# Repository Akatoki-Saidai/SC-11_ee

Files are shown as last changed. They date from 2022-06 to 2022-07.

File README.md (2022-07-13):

# SC-11_ee

## Arduino Pin使用番号

## 各種センサ動作確認結果

<table>
    <tr>
        <td width="20%" rowspan="3">三軸加速度</td>
        <td>analogRead()で電圧を読んでシリアルモニタに表示することはできた</td>
    </tr>
    <tr>
        <td>ふってみてデータを見た感じ変化はしているのでちゃんと取れてる？</td>
    </tr>
    <tr>
        <td>生データを表示しているのでわかりにくいので，[m/s^2]表記への変換が必要</td>
    </tr>
    <tr>
        <td rowspan="3">3軸角速度</td>
        <td>https://n.mtng.org/ele/arduino/tutorial017.html</td>
    </tr>
    <tr>
        <td>レジスタ等の変更が必要らしい</td>
    </tr>
    <tr>
        <td>単位は [°/sec]</td>
    </tr>
    <tr>
        <td rowspan="4">BME280</td>
        <td>高度がマイナスになるのは海面気圧が問題？</td>
    </tr>
    <tr>
        <td>SC-10で購入したSwitchScience製のBME280で動作確認</td>
    </tr>
    <tr>
        <td>高度は↓のサイトを参照</td>
    </tr>
    <tr>
        <td>https://keisan.casio.jp/exec/system/1203469826</td>
    </tr>
        <tr>
        <td rowspan="3">DRV8835</td>
        <td>モーターを動かす時間がなかったのでLEDでテスト</td>
    </tr>
    <tr>
        <td>「加速」「減速」以外はLEDでは正常に動作</td>
    </tr>
    <tr>
        <td>「加速」は「減速」は確認できなかった（エラーは出てない）</td>
    </tr>
</table>

## モード定義

この セクションでは各モードの概要を説明する．

#### 待機モード (Mode-N)

- このモードでは基本的には「何もしない」というモードですが，以下のセンサーのキャリブレーション・実行準備を実施します．
  
  - 加速度センサー
  - 角速度センサー
  - 地磁気センサー
  - ブラシレスモーター

- 以下の定義を全て満たした場合に `Mode-A` に移行するものとする．
  
  1. Arduino Nanoが起動してから `30 sec` 以上経過している
  
  2. CanSatの高度が `TBD m` 以上である
  
  3. CanSatが落下を検知
     
     :pencil2: 落下を検知とは：未定義

#### 機体安定モード (Mode-A)

- このモードでは機体を安定させることに特化した（またはそれのみを実施する）モードである．
  - 機体がある程度安定したら，`Mode-B`に移行し，機体を的確に制御する．

#### 機体制御モード (Mode-B)

- このモードでは機体を制御させることに特化した（またはそれのみを実施する）モードである．特に，ゴールへの制御を実行する．
  - 機体制御が困難になった場合は，`Mode-A`に移行する．
  - ゴールから`TBD`m以内に入ったら`Mode-F`

#### 最終着地モード (Mode-F)

- このモードではゴールとの距離を維持したまま下降することのみに特化したモード

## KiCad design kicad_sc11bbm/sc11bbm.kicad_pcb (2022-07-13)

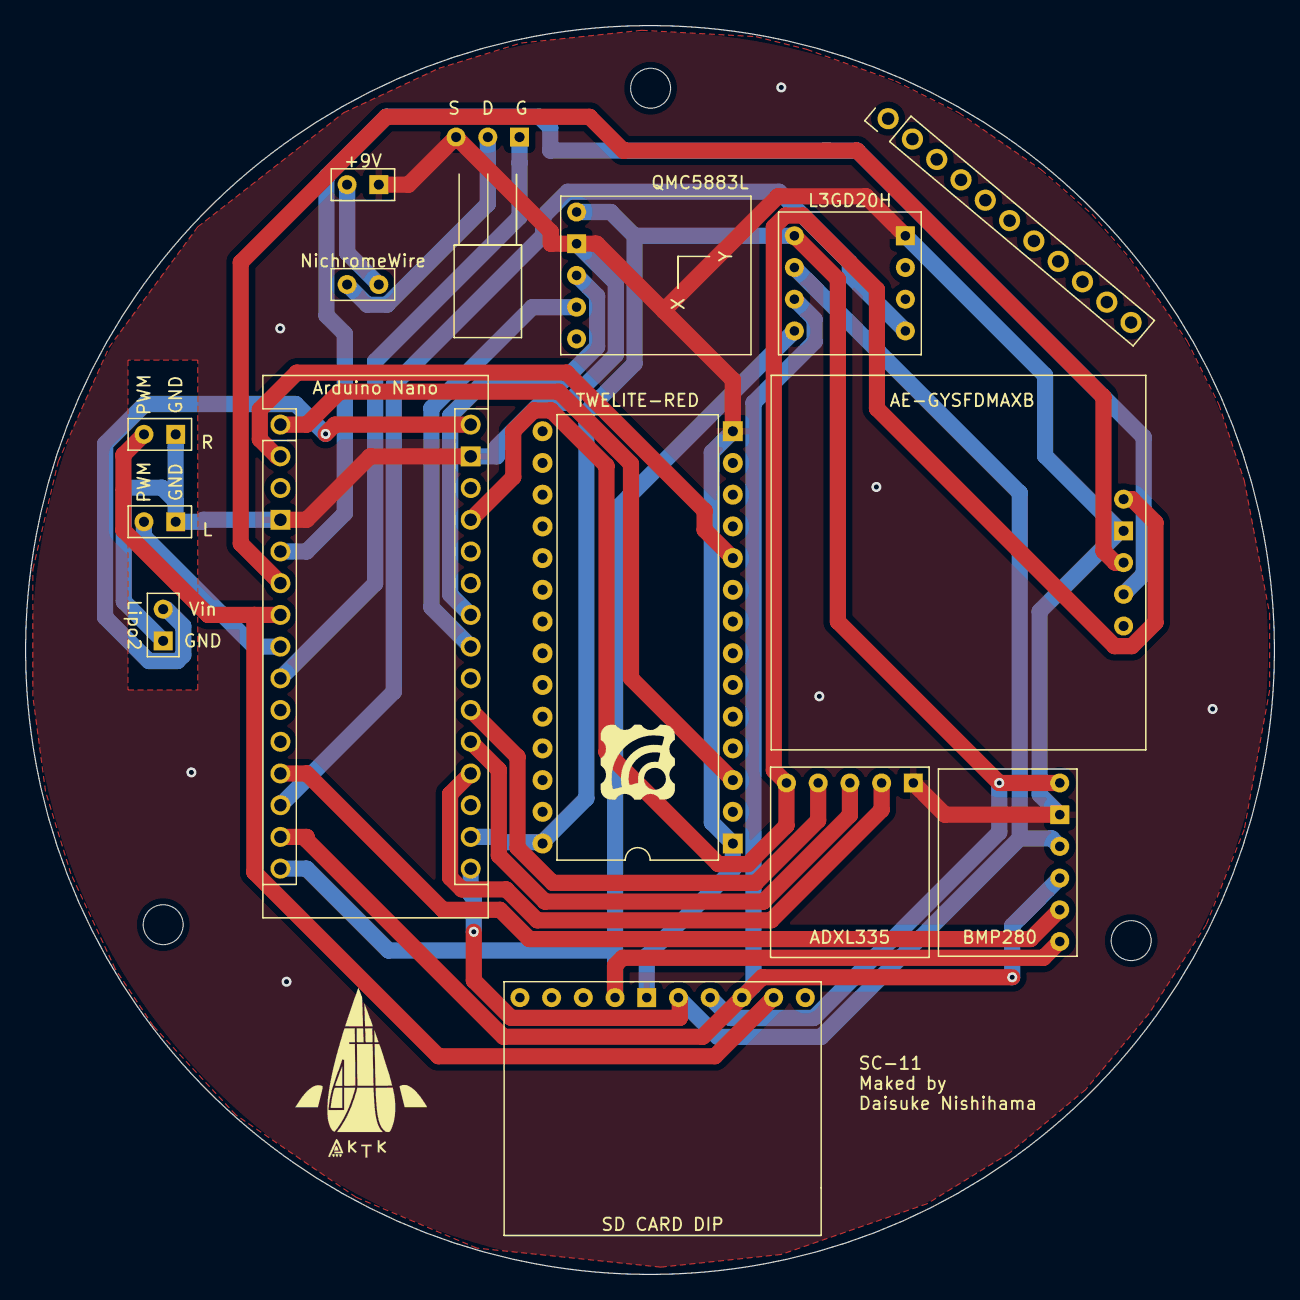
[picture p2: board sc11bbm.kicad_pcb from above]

Board: 2 copper layers, 100.0 x 100.0 mm, 17 parts (0 on the bottom side), 23 nets.

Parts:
A1: Arduino_Nano_v3.x; Arduino_Nano
BT1: Lipo2
BT2: +9V; power_9v
M1, M2, M3: MountingHole_3.2mm_M3_ISO14580
Q1: 2SK4017
RV1: NichromeWire
U1: ESC_R
U2: ESC_L
U3: L3GD20H
U4: QMC5883L
U5: BMP280
U6: MW-R-DP-W; DIP-28_W15.24mm
U7: AE-GYSFDMAXB
U8: ADXL335
U9: SD_CARD_DIP

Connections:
3V3: A1.17 (3V3), U3.1 (+V), U4.1 (VCC), U5.1 (VCC), U6.28 (VCC), U9.4 (VDD)
5V: A1.27 (+5V), U7.1 (5V), U8.1 (VCC)
A0: A1.19 (A0), U8.4 (Z_out)
A1: A1.20 (A1), U8.3 (Y_out)
A2: A1.21 (A2), U8.2 (X_out)
A4: A1.23 (A4), U4.4 (SDA)
A5: A1.24 (A5), U4.3 (SCL)
D2: A1.5 (D2), U7.4 (TXD)
D3: A1.6 (D3), U7.3 (RXD)
D4: A1.7 (D4), U1.1 (PWM), U9.2 (CD/DAT3)
D5: A1.8 (D5), U2.1 (PWM)
D6: A1.9 (D6), Q1.1 (G)
D9: A1.12 (D9), U5.5 (CSB)
D10: A1.13 (D10), U3.5 (CS)
D11: A1.14 (D11), U3.3 (SDA), U5.4 (SDA), U9.3 (CMD)
D12: A1.15 (D12), U3.4 (SA0), U5.6 (SDO), U9.7 (DAT0)
D13: A1.16 (D13), U3.2 (SCL), U5.3 (SCL), U9.5 (CLK)
GND: A1.4 (GND), A1.29 (GND), BT1.2 (-), BT2.2 (-), Q1.3 (S), U1.3 (GND), U2.3 (GND), U3.8 (GND), U4.2 (GND), U5.2 (GND), U6.1 (GND), U6.14 (GND), U7.2 (GND), U8.5 (GND), U9.6 (VSS)
Lipo2: A1.30 (VIN), BT1.1 (+)
unnamed: BT2.1 (+), RV1.2
unnamed: Q1.2 (D), RV1.1
RX: A1.2 (D0/RX), U6.10 (DIO6/TX)
TX: A1.1 (D1/TX), U6.3 (DIO7/RX)

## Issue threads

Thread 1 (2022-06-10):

加速度センサーが値を取得しない問題

ddd3h, 2022-06-10:
GitHubにコードを上げました．

加速度センサー用のテストコードですが，ハードが悪いのか（Arduino Nanoが悪いのか），ソフトが悪いのか（コードが悪いのか）調べられていません．

https://github.com/Akatoki-Saidai/SC-11_ee/blob/1a578c03ade2abc86e397201828683a99565d263/testcode/testcode_qyf0237/testcode_qyf0237.ino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

ddd3h, 2022-06-11:
ハードが原因と判明．
Arduino系列で動作確認済み

Closed 2022-06-11.

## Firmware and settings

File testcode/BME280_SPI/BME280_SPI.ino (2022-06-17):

#include <SPI.h>

//アドレス指定
#define CONFIG 0xF5
#define CTRL_MEAS 0xF4
#define CTRL_HUM 0xF2

//気温補正データ
uint16_t dig_T1;
int16_t  dig_T2;
int16_t  dig_T3;
 
//湿度補正データ
uint8_t  dig_H1;
int16_t  dig_H2;
uint8_t  dig_H3;
int16_t  dig_H4;
int16_t  dig_H5;
int8_t   dig_H6;
 
//気圧補正データ
uint16_t dig_P1;
int16_t  dig_P2;
int16_t  dig_P3;
int16_t  dig_P4;
int16_t  dig_P5;
int16_t  dig_P6;
int16_t  dig_P7;
int16_t  dig_P8;
int16_t  dig_P9;

unsigned char dac[26];
unsigned int i;

int32_t t_fine;
int32_t adc_P, adc_T, adc_H;

int32_t  temp_cal;
uint32_t humi_cal, pres_cal;
double temp, humi, pres ,alt;
double p0=1013.25;//海面気圧（hPa）

void setup() {
  //シリアル通信初期化
  Serial.begin(9600);//シリアル通信を9600bpsで初期化

  //SPI初期化
  SPI.begin();//SPIを初期化、SCK、MOSI、SSの各ピンの動作は出力、SCK、MOSIはLOW、SSはHIGH
  SPI.setDataMode(SPI_MODE0);//SPIモードを「0」に設定・CPOL(クロック位相)=0,CPHA(クロック極性)=0
  SPI.setBitOrder(MSBFIRST);//SPI送受信用のビットオーダーを「MSBFIRST」に設定

  //BME280動作設定
  digitalWrite(SS, LOW);//SSピンの出力をLOW(0V)に設定
  SPI.transfer(CONFIG & 0x7F);//動作設定
  SPI.transfer(0x00);//「単発測定」、「フィルタなし」、「SPI 4線式」
  digitalWrite(SS, HIGH);//SSピンの出力をHIGH(5V)に設定

  //BME280測定条件設定
  digitalWrite(SS, LOW);//SSピンの出力をLOW(0V)に設定
  SPI.transfer(CTRL_MEAS & 0x7F);//測定条件設定
  SPI.transfer(0x24);//「温度・気圧オーバーサンプリングx1」、「スリープモード」
  digitalWrite(SS, HIGH);//SSピンの出力をHIGH(5V)に設定

  //BME280温度測定条件設定
  digitalWrite(SS, LOW);//SSピンの出力をLOW(0V)に設定
  SPI.transfer(CTRL_HUM & 0x7F);//湿度測定条件設定
  SPI.transfer(0x01);//「湿度オーバーサンプリングx1」
  digitalWrite(SS, HIGH);//SSピンの出力をHIGH(5V)に設定

  //BME280補正データ取得
  digitalWrite(SS, LOW);//SSピンの出力をLOW(0V)に設定
  SPI.transfer(0x88 | 0x80);//出力データバイトを「補正データ」のアドレスに指定、書き込みフラグを立てる
  for (i=0; i<26; i++){
    dac[i] = SPI.transfer(0x00);//dacにSPIデバイス「BME280」のデータ読み込み
  }
  digitalWrite(SS, HIGH);//SSピンの出力をHIGH(5V)に設定

  dig_T1 = ((uint16_t)((dac[1] << 8) | dac[0]));
  dig_T2 = ((int16_t)((dac[3] << 8) | dac[2]));
  dig_T3 = ((int16_t)((dac[5] << 8) | dac[4]));

  dig_P1 = ((uint16_t)((dac[7] << 8) | dac[6]));
  dig_P2 = ((int16_t)((dac[9] << 8) | dac[8]));
  dig_P3 = ((int16_t)((dac[11] << 8) | dac[10]));
  dig_P4 = ((int16_t)((dac[13] << 8) | dac[12]));
  dig_P5 = ((int16_t)((dac[15] << 8) | dac[14]));
  dig_P6 = ((int16_t)((dac[17] << 8) | dac[16]));
  dig_P7 = ((int16_t)((dac[19] << 8) | dac[18]));
  dig_P8 = ((int16_t)((dac[21] << 8) | dac[20]));
  dig_P9 = ((int16_t)((dac[23] << 8) | dac[22]));

  dig_H1 = ((uint8_t)(dac[25]));

  digitalWrite(SS, LOW);//SSピンの出力をLOW(0V)に設定
  SPI.transfer(0xE1 | 0x80);//出力データバイトを「補正データ」のアドレスに指定、書き込みフラグを立てる
  for (i=0; i<7; i++){
    dac[i] = SPI.transfer(0x00);//dacにSPIデバイス「BM3280」のデータ読み込み
  }
  digitalWrite(SS, HIGH);//SSピンの出力をHIGH(5V)に設定

  dig_H2 = ((int16_t)((dac[1] << 8) | dac[0]));
  dig_H3 = ((uint8_t)(dac[2]));
  dig_H4 = ((int16_t)((dac[3] << 4) + (dac[4] & 0x0F)));
  dig_H5 = ((int16_t)((dac[5] << 4) + ((dac[4] >> 4) & 0x0F)));
  dig_H6 = ((int8_t)dac[6]);
  
  delay(1000);//1000msec待機(1秒待機)
}
 
void loop() {

  //BME280測定条件設定(1回測定後、スリープモード)
  digitalWrite(SS, LOW);//SSピンの出力をLOW(0V)に設定
  SPI.transfer(CTRL_MEAS & 0x7F);//測定条件設定
  SPI.transfer(0x25);//「温度・気圧オーバーサンプリングx1」、「1回測定後、スリープモード」
  digitalWrite(SS, HIGH);//SSピンの出力をHIGH(5V)に設定
  delay(10);//10msec待機

  //測定データ取得
  digitalWrite(SS, LOW);//SSピンの出力をLOW(0V)に設定
  SPI.transfer(0xF7 | 0x80);//出力データバイトを「気圧データ」のアドレスに指定、書き込みフラグを立てる
  for (i=0; i<8; i++){
    dac[i] = SPI.transfer(0x00);//dacにSPIデバイス「BME280」のデータ読み込み
  }
  digitalWrite(SS, HIGH);//SSピンの出力をHIGH(5V)に設定
  
  adc_P = ((uint32_t)dac[0] << 12) | ((uint32_t)dac[1] << 4) | ((dac[2] >> 4) & 0x0F);
  adc_T = ((uint32_t)dac[3] << 12) | ((uint32_t)dac[4] << 4) | ((dac[5] >> 4) & 0x0F);
  adc_H = ((uint32_t)dac[6] << 8) | ((uint32_t)dac[7]);
  
  pres_cal = BME280_compensate_P_int32(adc_P);//気圧データ補正計算
  temp_cal = BME280_compensate_T_int32(adc_T);//温度データ補正計算
  humi_cal = bme280_compensate_H_int32(adc_H);//湿度データ補正計算

  pres = (float)pres_cal / 100.0;//気圧データを実際の値に計算
  temp = (float)temp_cal / 100.0;//温度データを実際の値に計算
  humi = (float)humi_cal / 1024.0;//湿度データを実際の値に計算
  alt  = ((pow(p0/pres,-5.257)-1)*(temp + 273.15))/0.0065;

  //シリアルモニタ送信
  Serial.println("-----------------");
  Serial.print("Pressure:");//文字列「Pressure:」をシリアルモニタに送信
  Serial.print(pres);//「pres」をシリアルモニタに送信
  Serial.println("hPa ");//文字列「hPa 」をシリアルモニタに送信
  Serial.print("Temp:");//文字列「Temp:」をシリアルモニタに送信
  Serial.print(temp);//「temp」をシリアルモニタに送信
  Serial.println("°C ");//文字列「°C 」をシリアルモニタに送信
  Serial.print("Humidity:");//文字列「Humidity:」をシリアルモニタに送信
  Serial.print(humi);//「humi」をシリアルモニタに送信
  Serial.println("%");//文字列「%」をシリアルモニタに送信、改行
  Serial.print("Altitude：");
  Serial.print(alt);
  Serial.println("m");
  
  delay(1000);//1000msec待機(1秒待機)
}

//温度補正 関数
int32_t BME280_compensate_T_int32(int32_t adc_T)
{
  int32_t var1, var2, T;
  var1  = ((((adc_T>>3) - ((int32_t)dig_T1<<1))) * ((int32_t)dig_T2)) >> 11;
  var2  = (((((adc_T>>4) - ((int32_t)dig_T1)) * ((adc_T>>4) - ((int32_t)dig_T1))) >> 12) * ((int32_t)dig_T3)) >> 14;
  t_fine = var1 + var2;
  T  = (t_fine * 5 + 128) >> 8;
  return T;
}

//湿度補正 関数
uint32_t bme280_compensate_H_int32(int32_t adc_H)
{
  int32_t v_x1_u32r;

  v_x1_u32r = (t_fine - ((int32_t)76800)); 
  v_x1_u32r = (((((adc_H << 14) - (((int32_t)dig_H4) << 20) - (((int32_t)dig_H5) * v_x1_u32r)) + ((int32_t)16384)) >> 15) * (((((((v_x1_u32r * ((int32_t)dig_H6)) >> 10) * (((v_x1_u32r * ((int32_t)dig_H3)) >> 11) + ((int32_t)32768))) >> 10) + ((int32_t)2097152)) * 
((int32_t)dig_H2) + 8192) >> 14));
  v_x1_u32r = (v_x1_u32r - (((((v_x1_u32r >> 15) * (v_x1_u32r >> 15)) >> 7) * ((int32_t)dig_H1)) >> 4));
  v_x1_u32r = (v_x1_u32r < 0 ? 0 : v_x1_u32r);
  v_x1_u32r = (v_x1_u32r > 419430400 ? 419430400 : v_x1_u32r);
  return (uint32_t)(v_x1_u32r>>12);
}

//気圧補正 関数
uint32_t BME280_compensate_P_int32(int32_t adc_P)
{
  int32_t var1, var2;
  uint32_t p;
  var1 = (((int32_t)t_fine)>>1) - (int32_t)64000;
  var2 = (((var1>>2) * (var1>>2)) >> 11 ) * ((int32_t)dig_P6);
  var2 = var2 + ((var1*((int32_t)dig_P5))<<1);
  var2 = (var2>>2)+(((int32_t)dig_P4)<<16);
  var1 = (((dig_P3 * (((var1>>2) * (var1>>2)) >> 13 )) >> 3) + ((((int32_t)dig_P2) * var1)>>1))>>18;
  var1 =((((32768+var1))*((int32_t)dig_P1))>>15);
  if (var1 == 0)
  {
    return 0; // avoid exception caused by division by zero
  }
  p = (((uint32_t)(((int32_t)1048576)-adc_P)-(var2>>12)))*3125;
  if (p < 0x80000000)
  {
    p = (p << 1) / ((uint32_t)var1);
  }
  else
  {
    p = (p / (uint32_t)var1) * 2;
  }
  var1 = (((int32_t)dig_P9) * ((int32_t)(((p>>3) * (p>>3))>>13)))>>12;
  var2 = (((int32_t)(p>>2)) * ((int32_t)dig_P8))>>13;
  p = (uint32_t)((int32_t)p + ((var1 + var2 + dig_P7) >> 4));
  return p;
}

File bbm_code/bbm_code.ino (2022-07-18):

#include <Wire.h>
#include <SPI.h>
#include <SparkFunBME280.h>
#include <TinyGPS++.h>
#include <SoftwareSerial.h>
#include <DFRobot_QMC5883.h>

//GNSS
SoftwareSerial serialConsole(1,2); //RX=1ピン, TX=2ピン
TinyGPSPlus gps;

//BME280
const int SPI_CS_PIN = 10;
BME280 sensor;

//ADXL375
int xpin = A0;
int ypin = A1;
int zpin = A2;
int acX, acY, acZ;
double gX, gY, gZ;

//QMC5883
DFRobot_QMC5883 compass;

int minX = 0;
int maxX = 0;
int minY = 0;
int maxY = 0;
int offX = 0;
int offY = 0;

//gyro
short X, Y, Z;
float x, y, z;
const int L3GD20_CS = SS;
//const int SS = 10;      // 必ず 10 番を出力にすること
//const int MOSI = 11;
//const int MISO = 12;
//const int SCK  = 13;

const byte L3GD20_WHOAMI = 0x0f;
const byte L3GD20_CTRL1 = 0x20;
const byte L3GD20_CTRL2 = 0x21;
const byte L3GD20_CTRL3 = 0x22;
const byte L3GD20_CTRL4 = 0x23;
const byte L3GD20_CTRL5 = 0x24;
const byte L3GD20_X_L = 0x28;
const byte L3GD20_X_H = 0x29;
const byte L3GD20_Y_L = 0x2A;
const byte L3GD20_Y_H = 0x2B;
const byte L3GD20_Z_L = 0x2C;
const byte L3GD20_Z_H = 0x2D;

const byte L3GD20_RW = 0x80;
const byte L3GD20_MS = 0x40;

void L3GD20_write(byte reg, byte val)
{
  digitalWrite(L3GD20_CS, LOW);
  SPI.transfer(reg);
  SPI.transfer(val);
  digitalWrite(L3GD20_CS, HIGH);
}

byte L3GD20_read(byte reg)
{
  byte ret = 0;

  digitalWrite(L3GD20_CS, LOW);
  SPI.transfer(reg | L3GD20_RW);
  ret = SPI.transfer(0);
  digitalWrite(L3GD20_CS, HIGH);
  
  return ret;
}

void setup() {
  Serial.begin(115200);
  //setup for BMP280
  sensor.beginSPI(SPI_CS_PIN);
  //set up for GNSS at software serial
  serialConsole.begin(9600);
  //set up for QMC5883
    // Initialize Initialize QMC5883
    while (!compass.begin()){
      Serial.println("Could not find a valid QMC5883 sensor, check wiring!");
      delay(500);
    }
    if(compass.isHMC() ){
      Serial.println("Initialize HMC5883");
      compass.setRange(HMC5883L_RANGE_1_3GA);
      compass.setMeasurementMode(HMC5883L_CONTINOUS);
      compass.setDataRate(HMC5883L_DATARATE_15HZ);
      compass.setSamples(HMC5883L_SAMPLES_8);
    }else if(compass.isQMC()){
      Serial.println("Initialize QMC5883");
      compass.setRange(QMC5883_RANGE_2GA);
      compass.setMeasurementMode(QMC5883_CONTINOUS); 
      compass.setDataRate(QMC5883_DATARATE_50HZ);
      compass.setSamples(QMC5883_SAMPLES_8);
    }
  //gyro
  digitalWrite(SS, HIGH);
  pinMode(SS, OUTPUT);
  
  SPI.begin();
  SPI.setBitOrder(MSBFIRST);
  SPI.setClockDivider(SPI_CLOCK_DIV8); // 8MHz/8 = 1MHz; (max 10MHz)

  Serial.begin(9600);
  while (!Serial) {}

  Serial.println(L3GD20_read(L3GD20_WHOAMI), HEX); // should show D4

  L3GD20_write(L3GD20_CTRL1, B00001111);
                         //   |||||||+ X axis enable
                         //   ||||||+- Y axis enable
                         //   |||||+-- Z axis enable
                         //   ||||+--- PD: 0: power down, 1: active
                         //   ||++---- BW1-BW0: cut off 12.5[Hz]
                         //   ++------ DR1-DR0: ODR 95[HZ]
}

void loop() {
  while (serialConsole.available()){
    gps.encode(serialConsole.read());  
  }
  if (gps.location.isUpdated()){
    //time from GNSS
    Serial.print("time>>");
    Serial.print(gps.time.hour() + 9);
    Serial.print(":");
    Serial.print(gps.time.minute());
    Serial.print(":");
    Serial.print(gps.time.second());
    Serial.print("\n");
    //latitude from GNSS
    Serial.print("lat>>");
    Serial.print(gps.location.lat(),6);
    Serial.print("\n");
    //longitude from GNSS
    Serial.print("lng>>");
    Serial.print(gps.location.lng(),6);
    Serial.print("\n");
    //temperature from BMP280
    Serial.print("temp>>");
    Serial.print(sensor.readTempC(),2);
    Serial.print("\n");
    //pressure from BMP280
    Serial.print("pres>>");
    Serial.print(sensor.readFloatPressure() / 100.0 ,1);
    Serial.print("\n");
    //accelation from ADXL375
      //電圧の値を0~1023で取得
      acX = analogRead(xpin);
      acY = analogRead(ypin);
      acZ = analogRead(zpin);
      //電圧値を加速度(単位は重力加速度)に変換
      gX = 3*(acX-511.5)/511.5;
      gY = 3*(acY-511.5)/511.5;
      gZ = 3*(acZ-511.5)/511.5;
      //誤差補正
      Serial.print("acX>>");
      Serial.println((gX+0.92)/(-0.42));
      Serial.print("\n");
      Serial.print("acY>>");
      Serial.println((gY+0.93)/(-0.41));
      Serial.print("\n");
      Serial.print("acZ>>");
      Serial.println((gZ+0.94)/(-0.42));
      Serial.print("\n");
    //magnetism from QMC5883
    Vector mag = compass.readRaw();
    Serial.print("magX:");
    Serial.print(mag.XAxis-1000);
    Serial.print("\n");
    Serial.print("magY");    
    Serial.print(mag.YAxis-1000);
    Serial.print("\n");
    Serial.print("magZ:");
    Serial.print(mag.ZAxis-1000);
    Serial.print("\n");
    //gyro
    X = L3GD20_read(L3GD20_X_H);
  x = X = (X << 8) | L3GD20_read(L3GD20_X_L);
  Y = L3GD20_read(L3GD20_Y_H);
  y = Y = (Y << 8) | L3GD20_read(L3GD20_Y_L);
  Z = L3GD20_read(L3GD20_Z_H);
  z = Z = (Z << 8) | L3GD20_read(L3GD20_Z_L);
 
  x *= 0.00875; // +-250dps
  //x *= 0.0175;// +-500dps
  //x *= 0.07;  // +-2000dps
  y *= 0.00875; // +-250dps
  z *= 0.00875; // +-250dps
 
  Serial.print(X);    // X axis (reading)
  Serial.print("\t");
  Serial.print(Y);    // Y axis (reading)
  Serial.print("\t");
  Serial.print(Z);    // Z axis (reading)
  Serial.print("\t");
  Serial.print(x);    // X axis (deg/sec)
  Serial.print("\t");
  Serial.print(y);    // Y axis (deg/sec)
  Serial.print("\t");
  Serial.println(z);  // Z axis (deg/sec)
  }
  delay(1000);
}

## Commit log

2022-06-01 Made Kicad BBM folders
    KiCad共同開発用プロジェクトフォルダをアップロードしました．
    [sc11bbm.kicad_pcb, sc11bbm.kicad_sch]
2022-06-01 Just Creat README
    何も書いてません．とりあえず作っただけです．
2022-06-10 Create testcode_qyf0237.ino
    加速度センサー用のテストコードですが，ハードが悪いのか（Arduino Nanoが悪いのか），ソフトが悪いのか（コードが悪いのか）調べられていません．
2022-06-18 Rename "sc11bbm" "kicad_sc11bbm"
    [sc11bbm.kicad_pcb, sc11bbm.kicad_sch]
2022-06-18 Update gyro.ino
    delayを1000から10に変更した
2022-06-26 Update motor.ino
    ブラシレスモーター用のコードに変更
2022-07-06 Add some files related to Brushless motor
2022-07-10 Reference settings are not yet
    [sc11bbm.kicad_sch]
2022-07-10 Subtle changes to the schematic
    [sc11bbm.kicad_sch]
2022-07-11 Circuit diagram completed
    [sc11bbm.kicad_sch]
2022-07-11 Order completed for Board ver1.0
    [sc11bbm-B_Cu.gbr, sc11bbm-B_Mask.gbr, sc11bbm-B_Paste.gbr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]
2022-07-11 Made step file
    [sc11bbm.step]
2022-07-13 Revert "Merge branch 'main' into kicad"
    This reverts commit 1ffaabe5a03e4900a6120109884412335f5f846d, reversing
    changes made to 30488b6ef0ed4470b394fc2428748494f3e7c96e.
    [sc11bbm_test.kicad_sch]
2022-07-18 Update bbm_code.ino
    動作確認はまだできてないです
    申しわけない
    動くと信じて...
    to be continued...
